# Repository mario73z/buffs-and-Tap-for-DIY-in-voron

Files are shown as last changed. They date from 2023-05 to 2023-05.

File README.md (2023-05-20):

# Buffs-and-Tap-for-DIY-in-Voron
Inexpensive reinforcements with a tap for self-made for voron 2.4

Hello

Over three years ago I built my first voron, then still 2.2. I have it in a rather large size 450*3. As after these few years it is quite different from the current news, it's time to update the printer. New electronics M8P+CB1 and EBB Can 2209 arrived, also voron-tap.

After these updates and the resulting increase in the weight of the entire head, it turned out to be necessary to reduce the "max_accel" parameter and extend the entire printing process.
The main reason after the initial measurements turned out to be the plastic connections of the Tap (3D printing) and the connections of the bogies on the "Y" axis
There are several ready-made solutions on the CNC market for these stiffeners, but I like to do something myself. And this is how I designed the "X" and "Y" reinforcements and Tap.
I know that many people have their own plotters or mini cnc milling machines, or access to them. There are also a large number of people who like manual and can do something with their own hands, this is my post for you. For both modes, it is necessary to purchase a 2mm aluminum sheet, preferably PA9 or another with similar properties. And an aluminum pipe fi 10/1mm.
## XY reinforcements<br/>

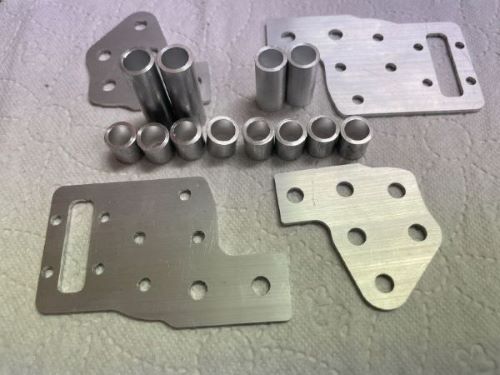
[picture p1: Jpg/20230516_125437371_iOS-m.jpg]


The only printed element is the stop end stop for X. The rest can be cut on cnc or by hand and thread M5 holes in the lower elements.
We need to cut the tube (precisely) <br/>
* 4x30mm <br/>
* 2x20mm <br/>
* 8x10mm <br/>

Screws for threaded elements <br/>
* M5x35 - 10 pcs <br/>
* M5x45-2pcs <br/>
* 10 washers M5x1mm <br/>

We twist and we have a rigid connection, it worked perfectly for me.
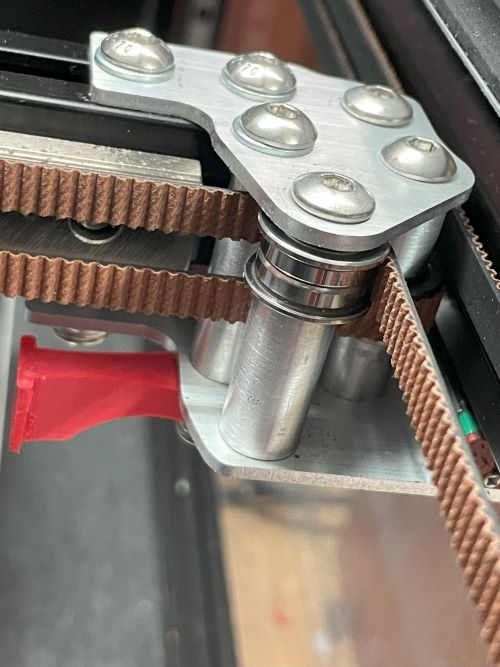
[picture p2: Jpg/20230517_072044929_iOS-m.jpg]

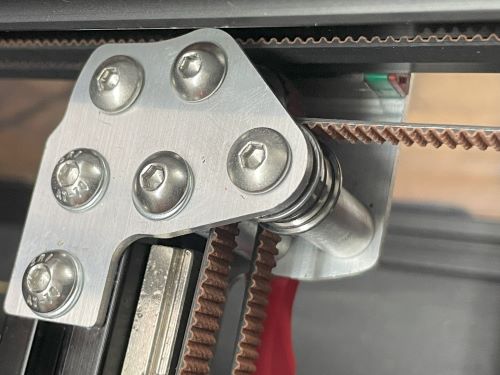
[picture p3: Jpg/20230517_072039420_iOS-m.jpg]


  Most questions will be answered by looking at the design in the CAD catalog file for DesignSpark Mechanical.<br/>

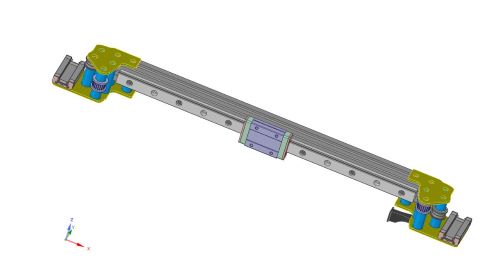
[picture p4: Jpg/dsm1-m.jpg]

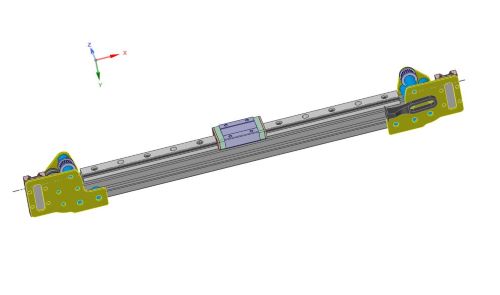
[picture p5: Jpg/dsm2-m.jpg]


## TAP<br/>
As before, we cut out elements from 2mm sheet metal and thread selected M3 holes. We print elements from the STL catalog. In some cases, it will probably be necessary to change the attachment element of the optical endstop for "Z", depending on its type. (I have my own design) You will need to change it in DesignSpark Mechanical. I pasted the magnet for the tap 7/3mm. <br/>

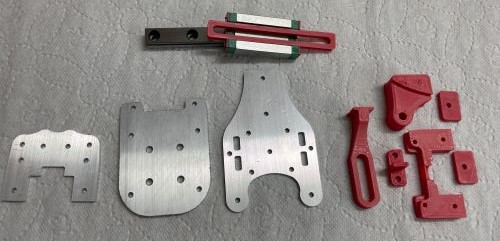
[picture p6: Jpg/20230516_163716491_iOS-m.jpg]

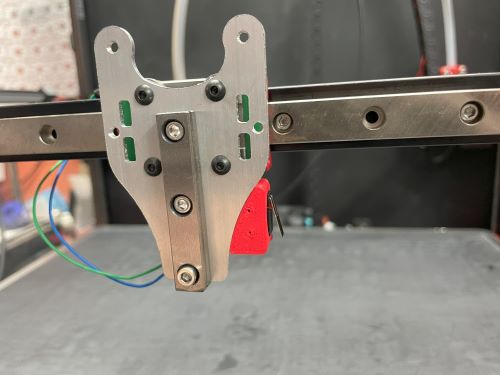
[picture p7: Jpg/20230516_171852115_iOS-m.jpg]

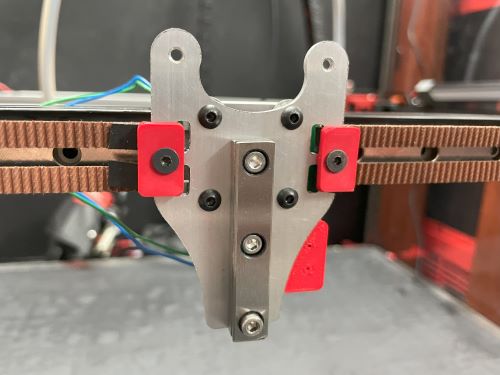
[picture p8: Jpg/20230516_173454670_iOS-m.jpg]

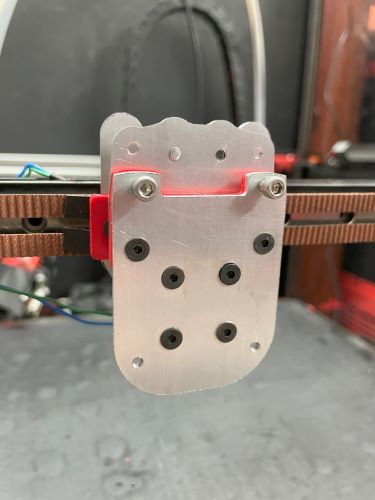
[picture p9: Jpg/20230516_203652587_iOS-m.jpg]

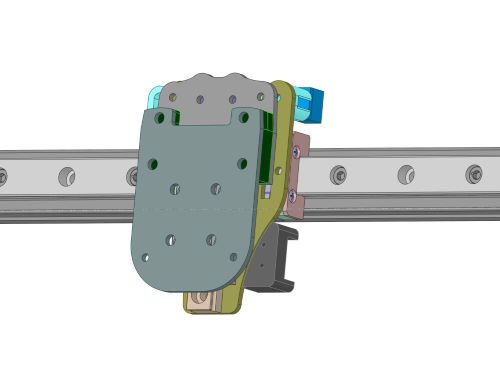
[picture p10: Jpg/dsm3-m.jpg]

Video of Tap by Mario

This project works perfectly for me. There is a noticeable change in the stiffness of the entire carriage with the extender.

Video of Tap by Mario

Some CAD design elements were downloaded from https://github.com/VoronDesign/

Although it is a simple project and works great for me, and its assembly was not difficult, I still strongly encourage you to familiarize yourself with the project and your own skills for such work before you decide to make changes. Reinforcements and Tap in the CNC version can be purchased ready-made on the market for several dozen euros. I am not responsible for any failures and possible defects. However, satisfaction from the work done brings a lot of satisfaction and, of course, this does not exclude possible substantive assistance on my part. Be careful and good luck. ;)

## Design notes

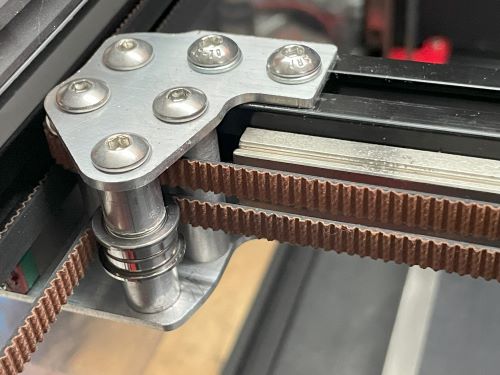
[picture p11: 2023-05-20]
Jpg/20230517_072100268_iOS-m.jpg

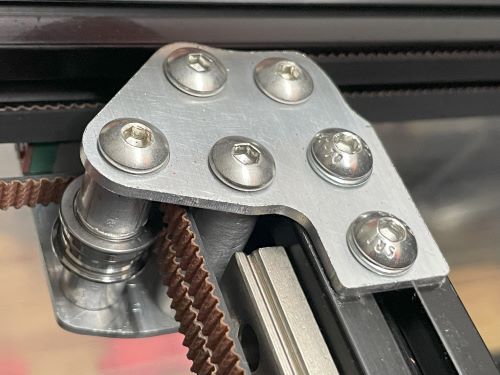
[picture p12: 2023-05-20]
Jpg/20230517_072051143_iOS-m.jpg

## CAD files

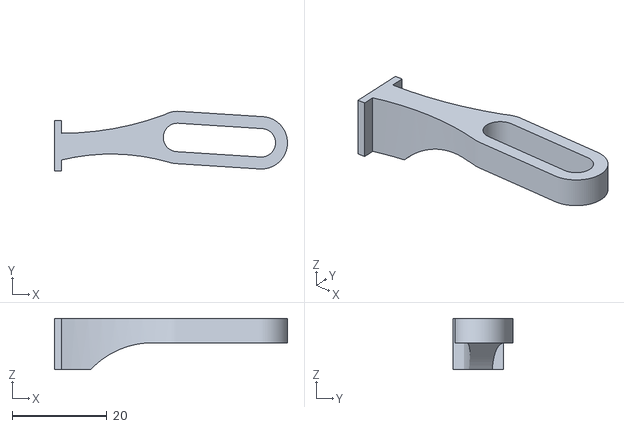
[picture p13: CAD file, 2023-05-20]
stl/ogranicznik-endstopu-x.stl
49.1 x 12.5 x 10.8

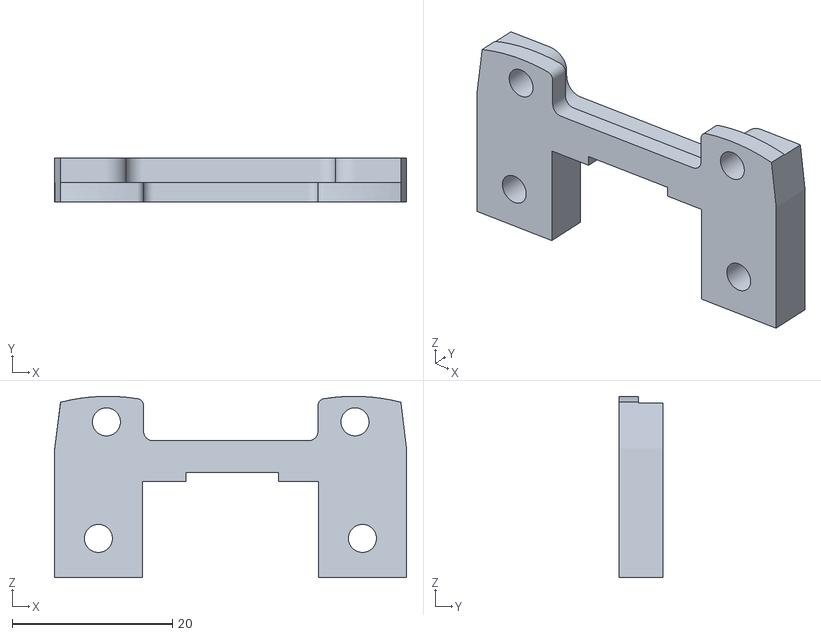
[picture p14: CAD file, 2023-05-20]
stl/dystans-tap.stl
44.0 x 5.44 x 22.7

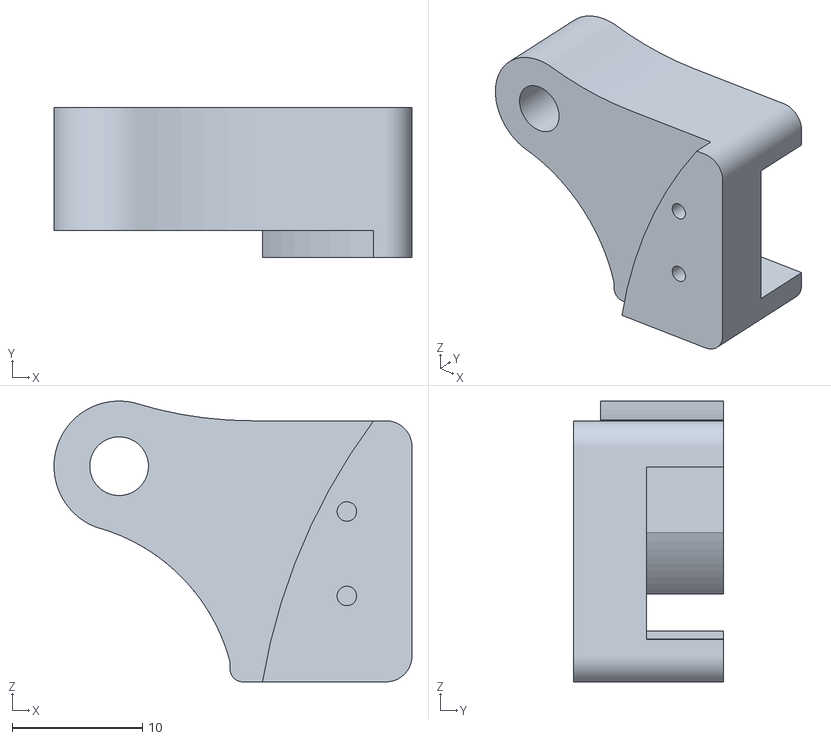
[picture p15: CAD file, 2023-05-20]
stl/uchwyt-endstop-x.stl
27.5 x 11.5 x 21.6

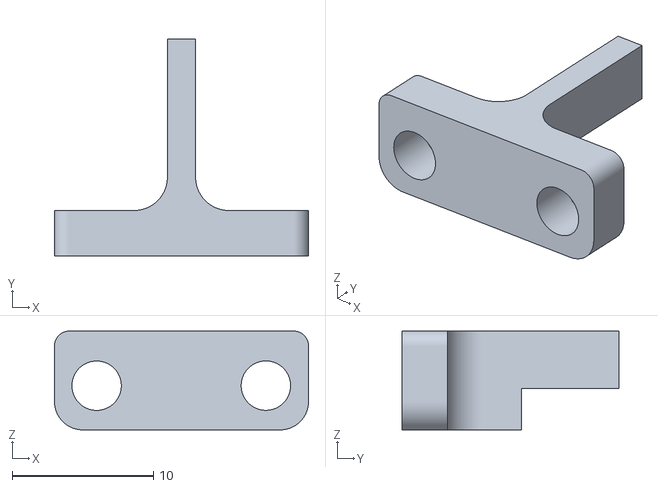
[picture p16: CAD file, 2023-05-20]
stl/przeslona-endstop-z.stl
18.0 x 15.4 x 7.00

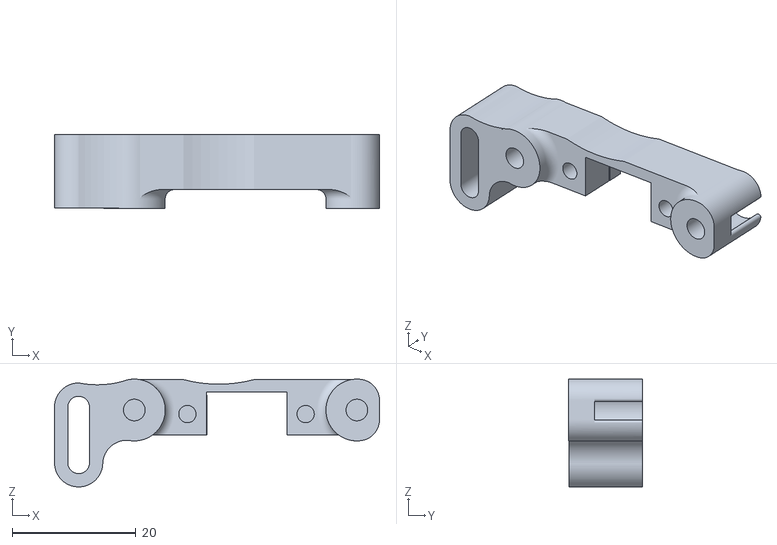
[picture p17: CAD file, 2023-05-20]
stl/uchwyt-endstop-z.stl
52.6 x 11.9 x 17.4
